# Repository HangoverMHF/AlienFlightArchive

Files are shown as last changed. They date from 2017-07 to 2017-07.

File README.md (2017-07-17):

## NOTE: This is an archival copy of the original CC BY-SA AlienFlight flight controllers. Preserved for posterity.

# AlienFlight

| [Classic FC](/Flight-Controllers/Classic#narrow-classic-flight-controller) | [F3 Quad FC](/Flight-Controllers/F3-V1/F3-Quad#f3-quad-brushed-v1-flight-controller) | [F3 Hexa FC](/Flight-Controllers/F3-V1/F3-Hexa#f3-hexa-brushed-v1-flight-controller) | [F3 Octo FC](/Flight-Controllers/F3-V1/F3-Octo#f3-octo-brushed-v1-flight-controller) |

## Objective

The goal of the AlienFlight project is to share some of my personal flight controller designs with fellow RC hobbyists, in hopes that this work might be useful. I want others to use, learn from, and enjoy this work in the same ways I have.

MAKE, SHARE, FLY!

### Contributing

Do you want to give back to this project? This project needs people who can help by providing:

* Board Specifications
* Documentation and Images
* How To tutorials

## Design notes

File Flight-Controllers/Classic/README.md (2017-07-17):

## NOTE: This is an archival copy of the original CC BY-SA AlienFlight flight controllers. Preserved for posterity.

## Narrow Classic Flight Controller
The Classic Narrow is an experimental flight controller designed to pilot Quadcopters using 7mm-8.5mm brushed motors. It features an Atmel Atmega 32u4 processor, MPU6050 Gyro/Accelerometer,  built in 9.5A ESCs, and a built in Bind button for easy binding.
### Narrow Classic Example Picture

Classic Narrow Classic-Narrow

#### Narrow Classic Specs
* MultiWii compatible
* Atmel Atmega 32u4 micro controller
* MPU6050 accelerometer/gyro sensor unit
* 4x 9.5A brushed ESCs (MOSFETS) - 2oz copper layers recommended
* Integrated USB port (side access)
* Serial connection for external DSM2/DSMX sat receiver (e.g. Spektrum SAT, OrangeRx R100 or Lemon RX)
* Alternate PPM connection for external receiver - Pin pulled out - untested
* Hardware bind button for easy binding
* Motor connections are at the corners for easy orientation with reduced wiring
* Dimensions:  31x25mm
* Direct operation from an single cell 3.7V Lipo battery
* 5V and 3.3V buck/boost regulators (5V out can be used to power accessories)
* Buzzer out on pin D8
* Single Sided - all components on the top layer

#### Build Files and Resources:

Schematic and board design ➜ [Narrow Classic 5V Eagle CAD Files](/Flight-Controllers/Classic "Classic Narrow Eagle CAD Files") 

This bare board can be made at ➜ [OSH Park](https://oshpark.com/ "OSH Park")

Stencils can be made at ➜ [OSH Stencils](https://www.oshstencils.com/ "OSH Stencils")

_**THESE FILES ARE BEING PROVIDED ''AS IS'' WITHOUT ANY EXPRESS OR IMPLIED WARRANTIES.**_

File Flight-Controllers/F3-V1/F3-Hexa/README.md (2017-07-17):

## NOTE: This is an archival copy of the original CC BY-SA AlienFlight flight controllers. Preserved for posterity.

## F3 Hexa Brushed V1 Flight Controller

The F3 Brushed Hexa is an experimental flight controller designed to pilot Quadcopters or Hexacopters using 7mm-8.5mm brushed motors. It features an ARM STM32 F3 processor, built in side USB for easy firmware flashing, and parameter editing, MPU6050 Gyro/Accelerometer, dual channel 5A ESCs, and a built in Bind switch for hassle free binding.

### F3 Hexa Brushed V1 Example Picture
(JMPR build pictured - Latest build uses tactile switches in place of jumpers)

F3 Hexa Brushed V1

#### F3 Hexa Brushed V1 Specifications

* Cleanflight/Betaflight compatible
* STM32 F3 MCU
* MPU6050 accelerometer/gyro sensor unit
* 4X dual channel 5A brushed ESCs (Mosfets)- 2oz copper layers recommended
* Direct programming connection via side USB
* (*) serial connection for external DSM2/DSMX sat receiver (e.g. Spektrum SAT, OrangeRx R100 or Lemon RX)
* Alternate PPM receiver connection (i.e. Deltang Rx31)
* Hardware bind button for easy binding
* Boot bind button for easy firmware flashing
* Motor connections oriented for self explanatory connection
* Dimensions: 27x31mm (use thin FR4 material for weight savings)
* Direct operation from an single cell lipo battery

#### Build Files and Resources:

Schematic and board design ➜ [F3 Hexa Brushed V1 Eagle CAD Files](/Flight-Controllers/F3-V1/F3-Hexa "F3 Hexa Brushed V1 Eagle CAD Files") 

This bare board can be made at ➜ [OSH Park](https://oshpark.com/ "OSH Park")

Stencils can be made at ➜ [OSH Stencils](https://www.oshstencils.com/ "OSH Stencils")

_**THESE FILES ARE BEING PROVIDED ''AS IS'' WITHOUT ANY EXPRESS OR IMPLIED WARRANTIES.**_

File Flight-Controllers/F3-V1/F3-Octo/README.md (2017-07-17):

## NOTE: This is an archival copy of the original CC BY-SA AlienFlight flight controllers. Preserved for posterity.

## F3 Octo Brushed V1 Flight Controller

The F3 Brushed Octo V1 is an experimental flight controller designed to pilot Quadcopters, Hexacopters, and even Octocopters using 7mm-8.5mm brushed motors. It features an ARM STM32 F3 processor,  built in USB for easy firmware flashing, and parameter editing,  MPU6050 Gyro/Accelerometer, 7A ESCs, and a built in Bind switch for easy binding.
### F3 Octo Brushed V1 Example Picture
(JMPR build pictured - Latest build uses tactile switches in place of jumpers)

F3 Octo Brushed V1

#### F3 Octo Brushed V1 Specifications

* Cleanflight compatible
* STM32 F3 MCU
* MPU6050 accelerometer/gyro sensor unit
* 4x 7A dual channel brushed ESCs (Mosfets) - 2 oz copper layers recommended
* Direct programming connection via side USB
* (*) serial connection for external DSM2/DSMX sat receiver (e.g. Spektrum SAT, OrangeRx R100 or Lemon RX)
* Alternate PPM receiver connection (i.e. Deltang Rx31)
* Hardware bind button for easy binding
* Boot button for easy firmware flashing
* Motor connections oriented for self explanatory connection
* Dimensions: 29x33mm (use thin FR4 material for weight savings)
* Direct operation from an single cell lipo battery
* All components arranged on the top layer

**NOTES:** Battery Voltage monitoring on 1S powered machines is not very effective (and is disabled by default in Cleanflight F3 firmware).

**Lost Model Alarm:** A small Buzzer with a low current draw (=<20mA) can be used in place of the VMON LED.  You can tie activation of this Buzzer to a switch on your Transmitter via the Beeper option, on the Cleanflight modes page.

**Octo Configuration:** In order to use Octo. you must select the custom mixer option on the Cleanflight Configuration page. Physical motor outputs are self explanatory.

#### Build Files and Resources:

Schematic and board design ➜ [F3 Octo Brushed V1 Eagle CAD Files](/Flight-Controllers/F3-V1/F3-Octo "F3 Octo Brushed V1 Eagle CAD Files") 

This bare board can be made at ➜ [OSH Park](https://oshpark.com/ "OSH Park")

Stencils can be made at ➜ [OSH Stencils](https://www.oshstencils.com/ "OSH Stencils")

_**THESE FILES ARE BEING PROVIDED ''AS IS'' WITHOUT ANY EXPRESS OR IMPLIED WARRANTIES.**_

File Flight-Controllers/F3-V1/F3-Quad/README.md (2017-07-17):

## NOTE: This is an archival copy of the original CC BY-SA AlienFlight flight controllers. Preserved for posterity.

## F3 Quad Brushed V1 Flight Controller

The F3 Quad Brushed V1 is an experimental flight controller designed to pilot Quadcopters using 7mm-8.5mm brushed motors. It features an ARM STM32 F3 processor, built in side USB for easy firmware flashing, and parameter editing, MPU6050 Gyro/Accelerometer, 9.5A ESCs, and a built in Bind button for hassle free transmitter binding.

### F3 Quad Brushed V1 Example Picture 
(JMPR build pictured - Latest build uses tactile switches in place of jumpers)

F3 Quad Brushed V1

#### F3 Quad Brushed V1 Specifications

* Cleanflight/Betaflight compatible
* STM32 F3 MCU
* MPU6050 accelerometer/gyro sensor unit
* 4x 9.5A brushed ESCs (Mosfets) - 2oz copper recommended
* Direct programming connection via Side USB
* (*) serial connection for external DSM2/DSMX sat receiver (e.g. Spektrum SAT, OrangeRx R100 or Lemon RX)
* Alternate PPM receiver connection (i.e. Deltang Rx31)
* Hardware bind button for easy binding
* Boot button for easy firmware flashing
* Motor connections oriented for self explanatory connection
* Dimensions: 26x30mm (use thin FR4 material for weight savings)
* Direct operation from an single cell lipo battery
* All components arranged on the top layer

#### Build Files and Resources:

Schematic and board design ➜ [F3 Quad Brushed V1 Eagle CAD Files](/Flight-Controllers/F3-V1/F3-Quad "F3 Quad Brushed V1 Eagle CAD Files") 

This bare board can be made at ➜ [OSH Park](https://oshpark.com/ "OSH Park")

Stencils can be made at ➜ [OSH Stencils](https://www.oshstencils.com/ "OSH Stencils")

_**THESE FILES ARE BEING PROVIDED ''AS IS'' WITHOUT ANY EXPRESS OR IMPLIED WARRANTIES.**_

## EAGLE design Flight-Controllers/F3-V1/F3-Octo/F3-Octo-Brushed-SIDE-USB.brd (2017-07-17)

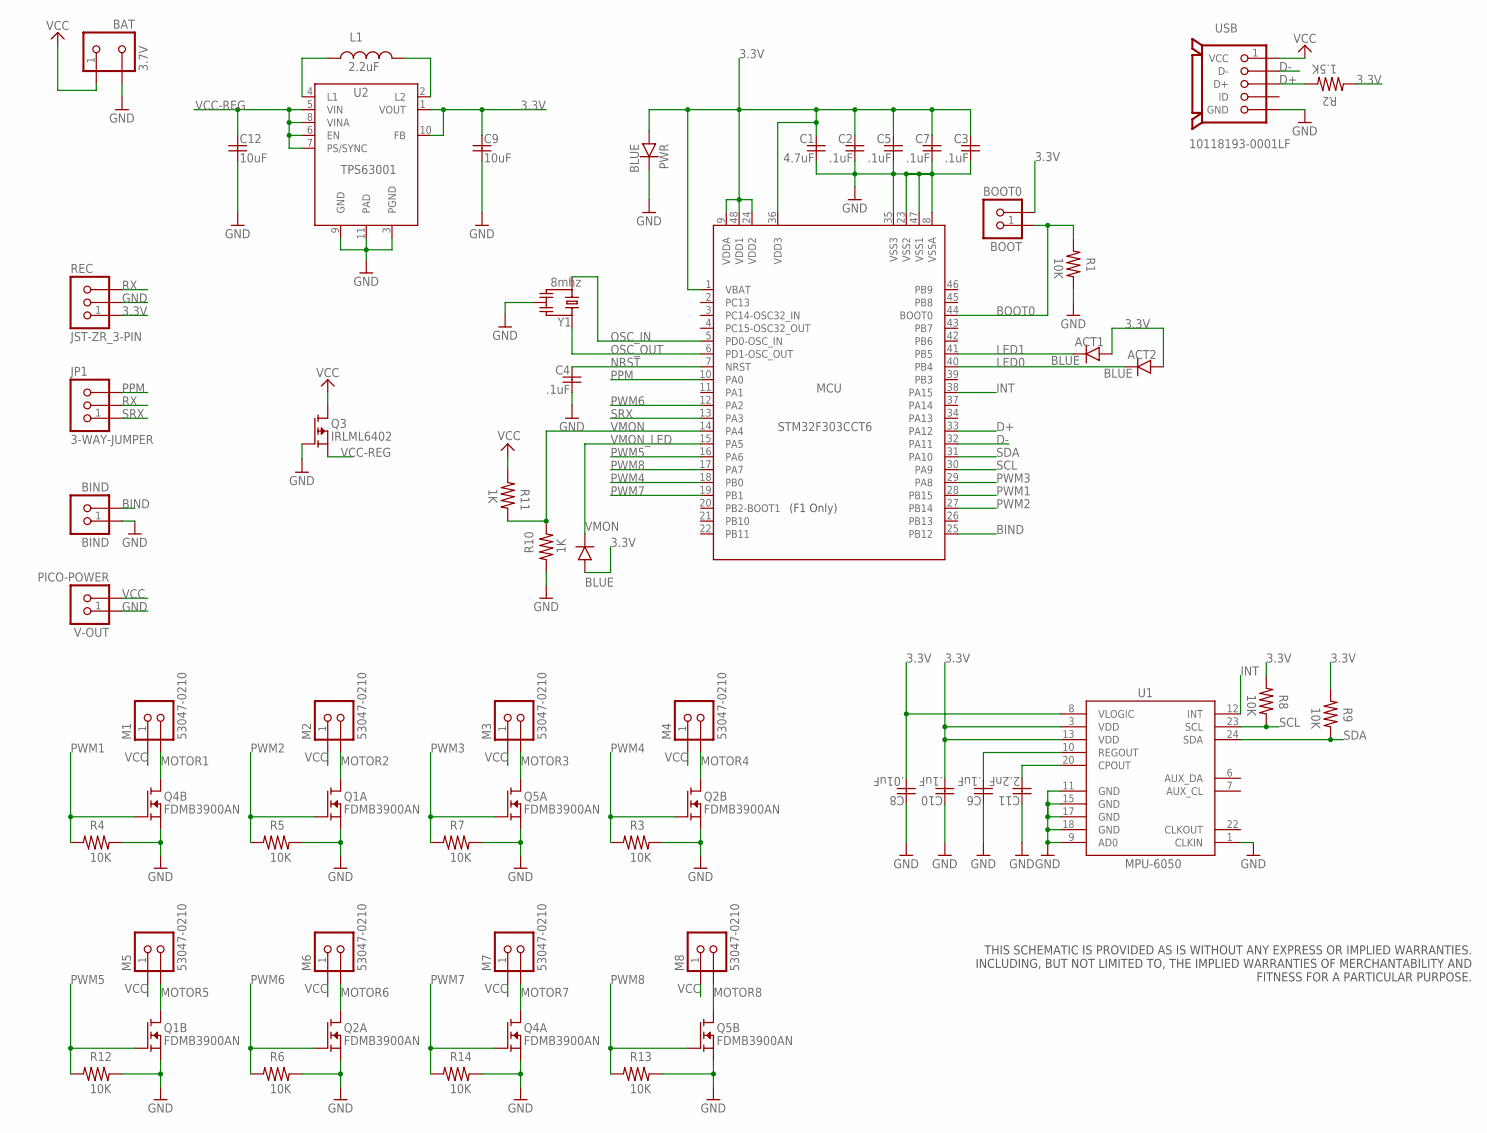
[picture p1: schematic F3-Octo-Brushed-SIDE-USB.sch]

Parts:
ACT1, ACT2: BLUE; SMD-CHIP-LED-0805
BAT: 3.7V; S2B-PH-K-S
BIND: BIND; B3U-1000P(M)
BOOT: BOOT0; B3U-1000P(M)
C1: 4.7uF; MUR-CAP-0603
C2, C3, C4, C5, C6, C7, C10: .1uF; MUR-CAP-0603
C8: .01uF; MUR-CAP-0603
C9, C12: 10uF; YUDEN-CAP-0805
C11: 2.2nF; MUR-CAP-0603
JP1: 3-WAY-JUMPER
L1: 2.2uF; NR301X
M1, M2, M3, M4, M5, M6, M7, M8: 53047-0210; PICO-53047-02
MCU: STM32F303CCT6; LQFP48-7X7
PWR: BLUE; SMD-CHIP-LED-0805
Q1, Q2, Q4, Q5: FDMB3900AN; 8-WDFN-DUAL
Q3: IRLML6402; SOT-23
R1, R3, R4, R5, R6, R7, R8, R9, R12, R13, R14: 10K; VISH-RES-0603
R2: 1.5K; VISH-RES-0603
R10, R11: 1K; VISH-RES-0603
REC: JST-ZR_3-PIN; S3B-ZR
U1: MPU-6050; QFN24-4X4
U2: TPS63001; VSON-N10
USB: 10118193-0001LF
V-OUT: PICO-POWER; PICO_1.25_.5MM
VMON: BLUE; SMD-CHIP-LED-0805
Y1: 8mhz; RESONATOR_8

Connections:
3.3V: ACT1.A, ACT2.A, BOOT.2, C1.1, C2.1, C3.1, C5.1, C7.1, C8.2, C9.1, C10.2, MCU.1 (VBAT), MCU.9 (VDDA), MCU.24 (VDD2), MCU.36 (VDD3), MCU.48 (VDD1), PWR.A, R2.2, R8.2, R9.2, REC.1, U1.3 (VDD), U1.8 (VLOGIC), U1.13 (VDD), U2.1 (VOUT), U2.10 (FB), VMON.A
BIND: BIND.2, MCU.25 (PB12)
BOOT0: BOOT.1, MCU.44 (BOOT0), R1.2
D+: MCU.33 (PA12), R2.1, USB.3 (D+)
D-: MCU.32 (PA11), USB.2 (D-)
GND: BAT.2, BIND.1, C1.2, C2.2, C3.2, C4.2, C5.2, C6.1, C7.2, C8.1, C9.2, C10.1, C11.1, C12.2, MCU.8 (VSSA), MCU.23 (VSS2), MCU.35 (VSS3), MCU.47 (VSS1), PWR.C, Q1.1@S1 (S), Q1.3@S1 (S), Q2.1@S1 (S), Q2.3@S1 (S), Q3.1 (G), Q4.1@S1 (S), Q4.3@S1 (S), Q5.1@S1 (S), Q5.3@S1 (S), R1.1, R3.1, R4.1, R5.1, R6.1, R7.1, R10.2, R12.1, R13.1, R14.1, REC.2, U1.1 (CLKIN), U1.9 (AD0), U1.11 (GND), U1.15 (GND), U1.17 (GND), U1.18 (GND), U2.3 (PGND), U2.9 (GND), U2.11 (PAD), USB.5 (GND), USB.GND, USB.GND2 (GND), USB.HOLE1 (GND), USB.HOLE2 (GND), V-OUT.1, Y1.2
INT: MCU.38 (PA15), U1.12 (INT)
LED0: ACT2.C, MCU.40 (PB4)
LED1: ACT1.C, MCU.41 (PB5)
MOTOR1: M1.2, Q4.5+6 (D)
MOTOR2: M2.2, Q1.7+8 (D)
MOTOR3: M3.2, Q5.7+8 (D)
MOTOR4: M4.2, Q2.5+6 (D)
MOTOR5: M5.2, Q1.5+6 (D)
MOTOR6: M6.2, Q2.7+8 (D)
MOTOR7: M7.2, Q4.7+8 (D)
MOTOR8: M8.2, Q5.5+6 (D)
unnamed: C6.2, U1.10 (REGOUT)
unnamed: C11.2, U1.20 (CPOUT)
unnamed: L1.2, U2.2 (L2)
unnamed: L1.1, U2.4 (L1)
NRST: C4.1, MCU.7 (NRST)
OSC_IN: MCU.5 (PD0-OSC_IN), Y1.3
OSC_OUT: MCU.6 (PD1-OSC_OUT), Y1.1
PPM: JP1.3, MCU.10 (PA0)
PWM1: MCU.28 (PB15), Q4.4@G2 (G), R4.2
PWM2: MCU.27 (PB14), Q1.2@G1 (G), R5.2
PWM3: MCU.29 (PA8), Q5.2@G1 (G), R7.2
PWM4: MCU.18 (PB0), Q2.4@G2 (G), R3.2
PWM5: MCU.16 (PA6), Q1.4@G2 (G), R12.2
PWM6: MCU.12 (PA2), Q2.2@G1 (G), R6.2
PWM7: MCU.19 (PB1), Q4.2@G1 (G), R14.2
PWM8: MCU.17 (PA7), Q5.4@G2 (G), R13.2
RX: JP1.2, REC.3
SCL: MCU.30 (PA9), R8.1, U1.23 (SCL)
SDA: MCU.31 (PA10), R9.1, U1.24 (SDA)
SRX: JP1.1, MCU.13 (PA3)
VCC: BAT.1, M1.1, M2.1, M3.1, M4.1, M5.1, M6.1, M7.1, M8.1, Q3.3 (D), R11.2, USB.1 (VCC), V-OUT.2
VCC-REG: C12.1, Q3.2 (S), U2.5 (VIN), U2.6 (EN), U2.7 (PS/SYNC), U2.8 (VINA)
VMON: MCU.14 (PA4), R10.1, R11.1
VMON_LED: MCU.15 (PA5), VMON.C

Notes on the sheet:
THIS SCHEMATIC IS PROVIDED AS IS WITHOUT ANY EXPRESS OR IMPLIED WARRANTIES. INCLUDING, BUT NOT LIMITED TO, THE IMPLIED WARRANTIES OF MERCHANTABILITY AND FITNESS FOR A PARTICULAR PURPOSE.

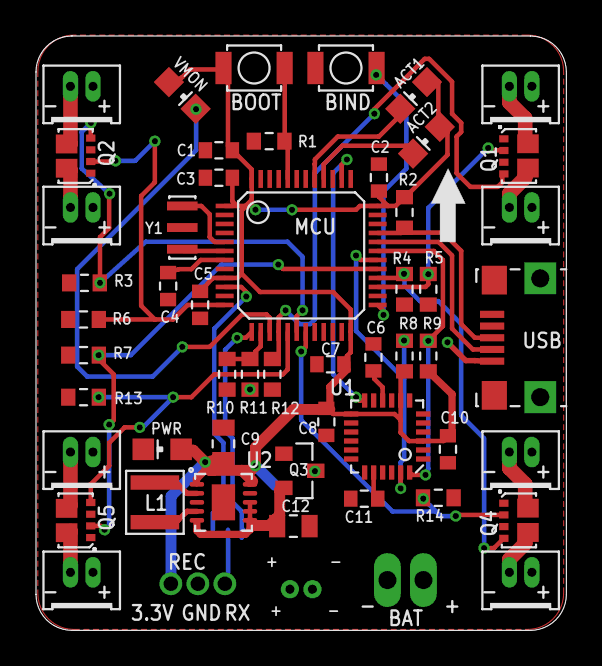
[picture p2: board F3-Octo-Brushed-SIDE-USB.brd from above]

Board: 2 copper layers, 29.5 x 33.0 mm, 56 parts (1 on the bottom side), 41 nets.

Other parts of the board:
U$2: ARROW

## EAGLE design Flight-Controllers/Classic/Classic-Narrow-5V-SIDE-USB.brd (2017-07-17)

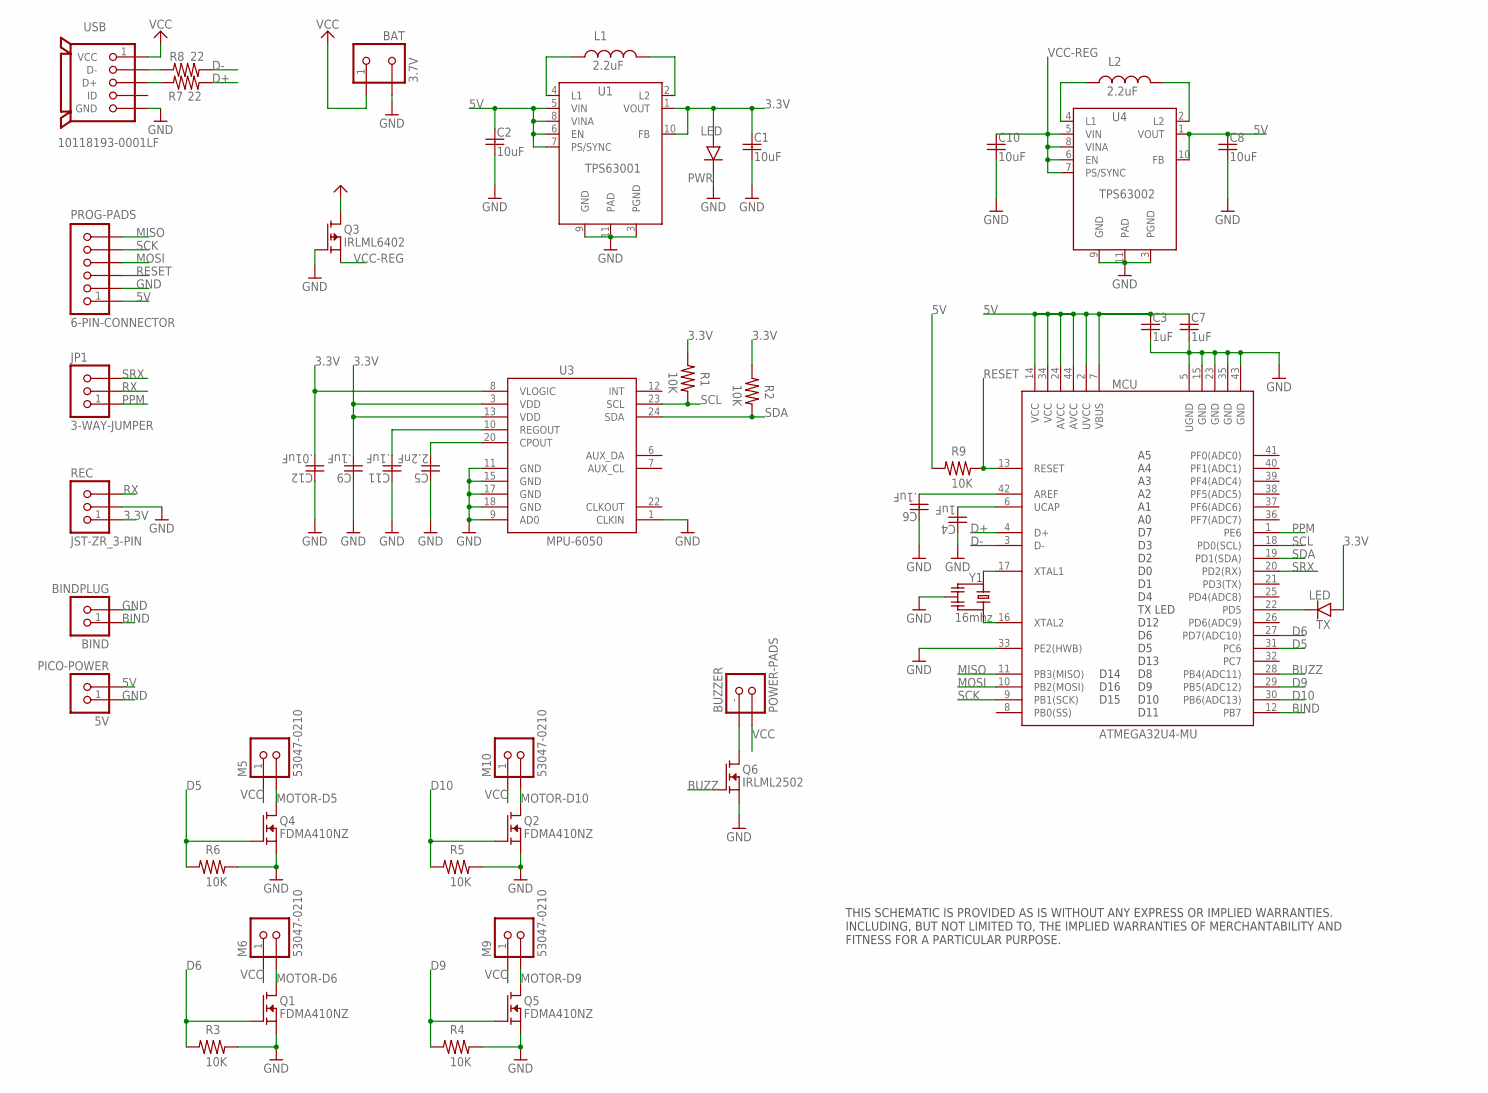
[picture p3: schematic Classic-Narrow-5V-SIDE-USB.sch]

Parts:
5V: PICO-POWER; PICO_1.25_.5MM
BAT: 3.7V; S2B-PH-K-S
BIND: BINDPLUG; B3U-1000P(M)
BUZZER: POWER-PADS; POW-PADS
C1, C2, C8, C10: 10uF; YUDEN-CAP-0805
C3, C4, C7: 1uF; MUR-CAP-0603
C5: 2.2nF; MUR-CAP-0603
C6, C9, C11: .1uF; MUR-CAP-0603
C12: .01uF; MUR-CAP-0603
JP1: 3-WAY-JUMPER
L1, L2: 2.2uF; NR301X
M5, M6, M9, M10: 53047-0210; PICO-53047-02
MCU: ATMEGA32U4-MU; QFN44-7X7
PROG-PADS: 6-PIN-CONNECTOR; B6B-ZR
PWR: LED; SMD-CHIP-LED-0805
Q1, Q2, Q4, Q5: FDMA410NZ; MICROFET-2X2
Q3: IRLML6402; SOT-23
Q6: IRLML2502; SOT-23
R1, R2, R3, R4, R5, R6, R9: 10K; VISH-RES-0603
R7, R8: 22; VISH-RES-0603
REC: JST-ZR_3-PIN; S3B-ZR
TX: LED; SMD-CHIP-LED-0805
U1: TPS63001; VSON-N10
U3: MPU-6050; QFN24-4X4
U4: TPS63002; VSON-N10
USB: 10118193-0001LF
Y1: 16mhz; RESONATOR_16

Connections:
3.3V: C1.1, C9.2, C12.2, PWR.A, R1.2, R2.2, REC.1, TX.A, U1.1 (VOUT), U1.10 (FB), U3.3 (VDD), U3.8 (VLOGIC), U3.13 (VDD)
5V: 5V.2, C2.1, C3.1, C7.1, C8.1, MCU.2 (UVCC), MCU.7 (VBUS), MCU.14 (VCC), MCU.24 (AVCC), MCU.34 (VCC), MCU.44 (AVCC), PROG-PADS.1, R9.2, U1.5 (VIN), U1.6 (EN), U1.7 (PS/SYNC), U1.8 (VINA), U4.1 (VOUT), U4.10 (FB)
AREF: C6.2, MCU.42 (AREF)
BIND: BIND.1, MCU.12 (PB7)
BUZZ: MCU.28 (PB4(ADC11)), Q6.1 (G)
D5: MCU.31 (PC6), Q4.G, R6.2
D6: MCU.27 (PD7(ADC10)), Q1.G, R3.2
D9: MCU.29 (PB5(ADC12)), Q5.G, R4.2
D10: MCU.30 (PB6(ADC13)), Q2.G, R5.2
D+: MCU.4 (D+), R7.1
D-: MCU.3 (D-), R8.1
GND: 5V.1, BAT.2, BIND.2, C1.2, C2.2, C3.2, C4.1, C5.1, C6.1, C7.2, C8.2, C9.1, C10.2, C11.1, C12.1, MCU.5 (UGND), MCU.15 (GND), MCU.23 (GND), MCU.33 (PE2(HWB)), MCU.35 (GND), MCU.43 (GND), PROG-PADS.2, PWR.C, Q1.S, Q1.S1 (S), Q2.S, Q2.S1 (S), Q3.1 (G), Q4.S, Q4.S1 (S), Q5.S, Q5.S1 (S), Q6.2 (S), R3.1, R4.1, R5.1, R6.1, REC.2, U1.3 (PGND), U1.9 (GND), U1.11 (PAD), U3.1 (CLKIN), U3.9 (AD0), U3.11 (GND), U3.15 (GND), U3.17 (GND), U3.18 (GND), U4.3 (PGND), U4.9 (GND), U4.11 (PAD), USB.5 (GND), USB.GND, USB.GND2 (GND), USB.HOLE1 (GND), USB.HOLE2 (GND), Y1.2
MISO: MCU.11 (PB3(MISO)), PROG-PADS.6
MOSI: MCU.10 (PB2(MOSI)), PROG-PADS.4
MOTOR-D5: M5.2, Q4.D, Q4.D1 (D), Q4.D2 (D), Q4.D3 (D), Q4.D4 (D)
MOTOR-D6: M6.2, Q1.D, Q1.D1 (D), Q1.D2 (D), Q1.D3 (D), Q1.D4 (D)
MOTOR-D9: M9.2, Q5.D, Q5.D1 (D), Q5.D2 (D), Q5.D3 (D), Q5.D4 (D)
MOTOR-D10: M10.2, Q2.D, Q2.D1 (D), Q2.D2 (D), Q2.D3 (D), Q2.D4 (D)
unnamed: MCU.17 (XTAL1), Y1.1
unnamed: MCU.16 (XTAL2), Y1.3
unnamed: R7.2, USB.3 (D+)
unnamed: C4.2, MCU.6 (UCAP)
unnamed: C11.2, U3.10 (REGOUT)
unnamed: R8.2, USB.2 (D-)
unnamed: MCU.22 (PD5), TX.C
unnamed: C5.2, U3.20 (CPOUT)
unnamed: L1.2, U1.2 (L2)
unnamed: BUZZER.- (1), Q6.3 (D)
unnamed: L1.1, U1.4 (L1)
unnamed: L2.2, U4.2 (L2)
unnamed: L2.1, U4.4 (L1)
PPM: JP1.1, MCU.1 (PE6)
RESET: MCU.13 (RESET), PROG-PADS.3, R9.1
RX: JP1.2, REC.3
SCK: MCU.9 (PB1(SCK)), PROG-PADS.5
SCL: MCU.18 (PD0(SCL)), R1.1, U3.23 (SCL)
SDA: MCU.19 (PD1(SDA)), R2.1, U3.24 (SDA)
SRX: JP1.3, MCU.20 (PD2(RX))
VCC: BAT.1, BUZZER.+ (2), M5.1, M6.1, M9.1, M10.1, Q3.3 (D), USB.1 (VCC)
VCC-REG: C10.1, Q3.2 (S), U4.5 (VIN), U4.6 (EN), U4.7 (PS/SYNC), U4.8 (VINA)

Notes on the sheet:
THIS SCHEMATIC IS PROVIDED AS IS WITHOUT ANY EXPRESS OR IMPLIED WARRANTIES. INCLUDING, BUT NOT LIMITED TO, THE IMPLIED WARRANTIES OF MERCHANTABILITY AND FITNESS FOR A PARTICULAR PURPOSE.

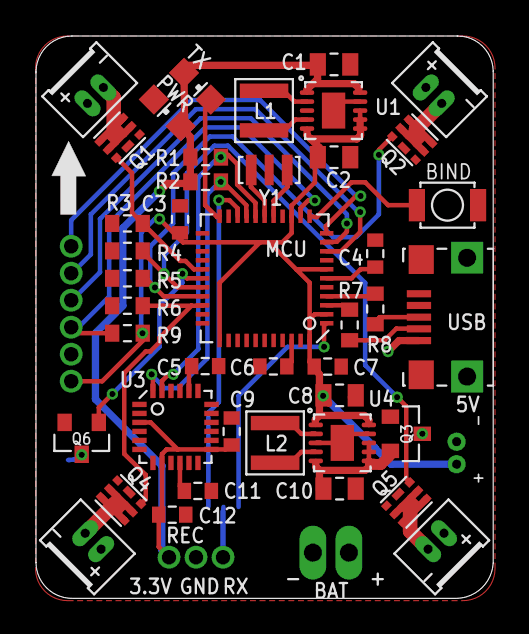
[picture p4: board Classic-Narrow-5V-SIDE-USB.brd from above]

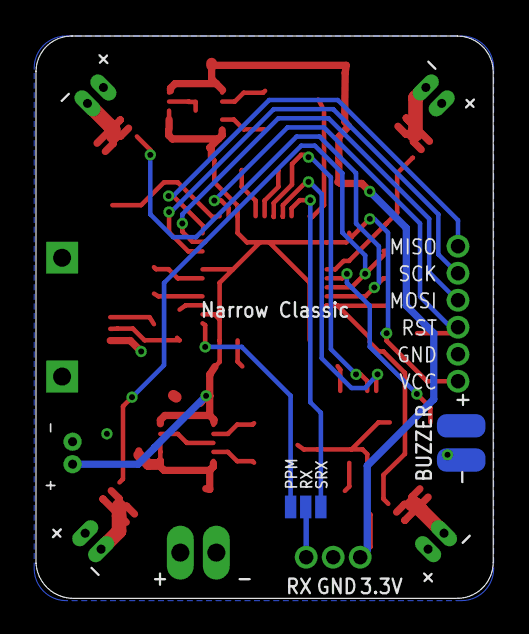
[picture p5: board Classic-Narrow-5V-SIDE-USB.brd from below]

Board: 2 copper layers, 25.4 x 31.2 mm, 49 parts (2 on the bottom side), 40 nets.

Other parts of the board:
U$1: ARROW

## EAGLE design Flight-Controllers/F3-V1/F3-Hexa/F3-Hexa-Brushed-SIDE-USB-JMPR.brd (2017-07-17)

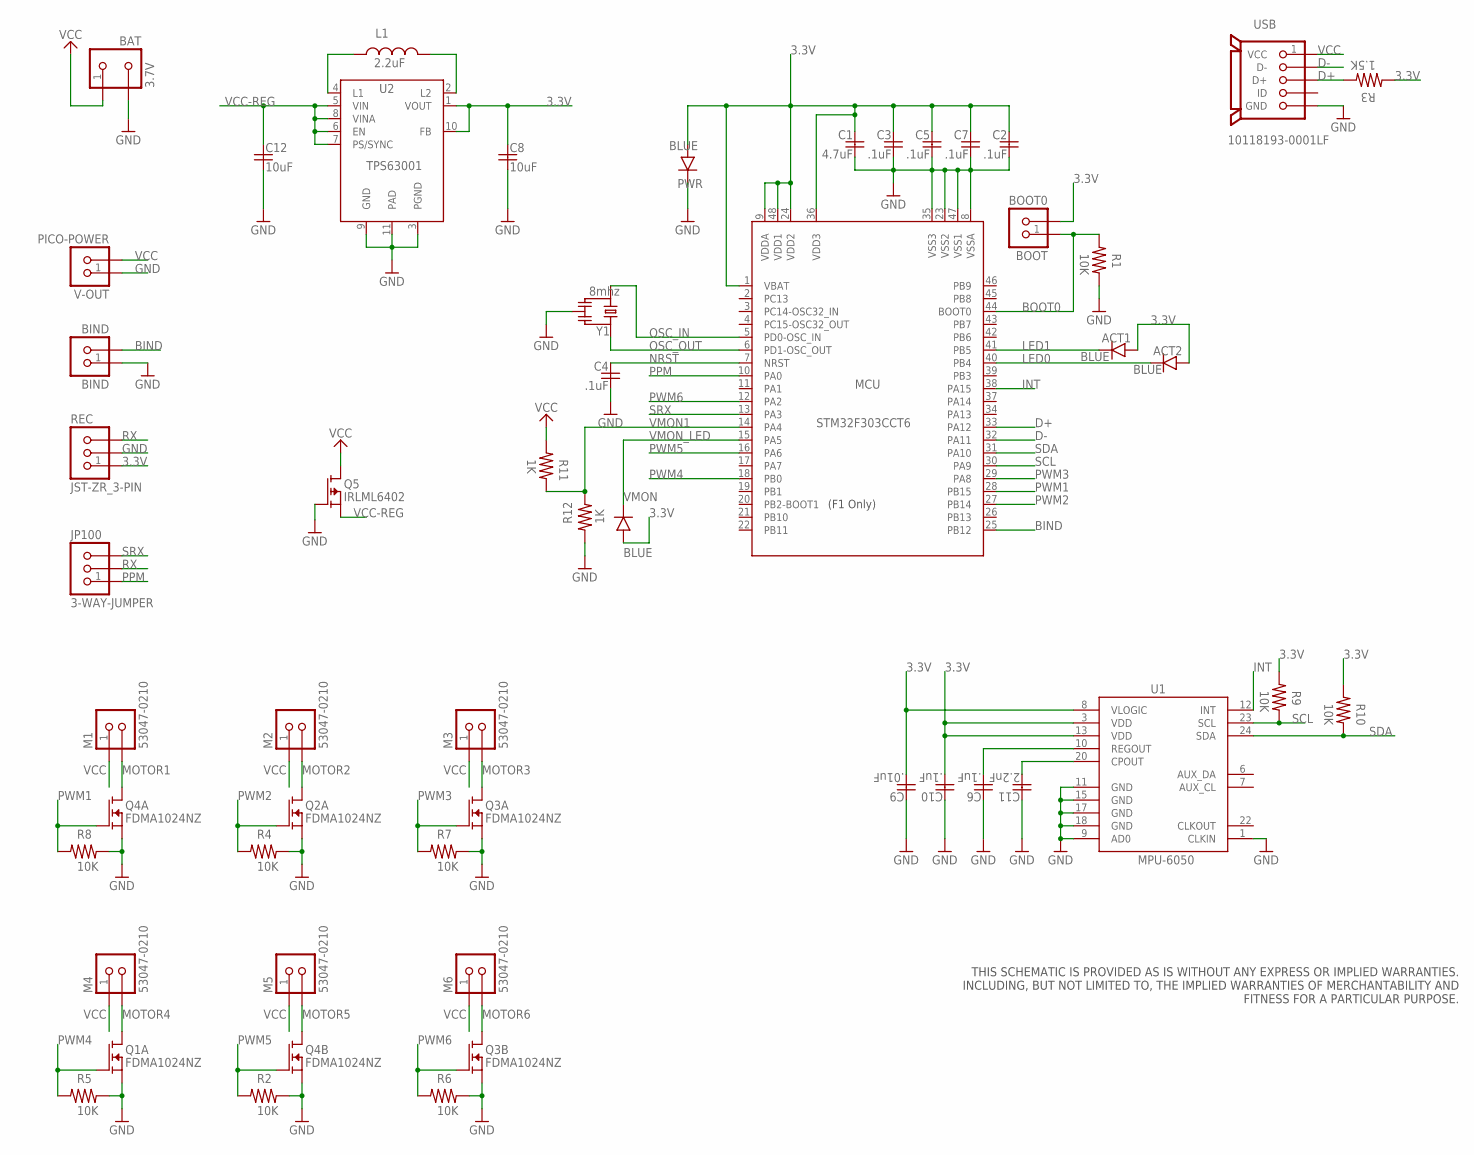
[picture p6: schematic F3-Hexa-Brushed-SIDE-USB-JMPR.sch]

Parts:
ACT1, ACT2: BLUE; SMD-CHIP-LED-0805
BAT: 3.7V; S2B-PH-K-S
BIND: BIND; 1.27MM-PINHEADX2
BOOT: BOOT0; 1.27MM-PINHEADX2
C1: 4.7uF; MUR-CAP-0603
C2, C3, C4, C5, C6, C7, C10: .1uF; MUR-CAP-0603
C8, C12: 10uF; YUDEN-CAP-0805
C9: .01uF; MUR-CAP-0603
C11: 2.2nF; MUR-CAP-0603
JP100: 3-WAY-JUMPER
L1: 2.2uF; NR301X
M1, M2, M3, M4, M5, M6: 53047-0210; PICO-53047-02
MCU: STM32F303CCT6; LQFP48-7X7
PWR: BLUE; SMD-CHIP-LED-0805
Q1, Q2, Q3, Q4: FDMA1024NZ; MICROFET-2X2_DUAL
Q5: IRLML6402; SOT-23
R1, R2, R4, R5, R6, R7, R8, R9, R10: 10K; VISH-RES-0603
R3: 1.5K; VISH-RES-0603
R11, R12: 1K; VISH-RES-0603
REC: JST-ZR_3-PIN; S3B-ZR
U1: MPU-6050; QFN24-4X4
U2: TPS63001; VSON-N10
USB: 10118193-0001LF
V-OUT: PICO-POWER; PICO_1.25_.5MM
VMON: BLUE; SMD-CHIP-LED-0805
Y1: 8mhz; RESONATOR_8

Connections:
3.3V: ACT1.A, ACT2.A, BOOT.2, C1.1, C2.1, C3.1, C5.1, C7.1, C8.1, C9.2, C10.2, MCU.1 (VBAT), MCU.9 (VDDA), MCU.24 (VDD2), MCU.36 (VDD3), MCU.48 (VDD1), PWR.A, R3.2, R9.2, R10.2, REC.1, U1.3 (VDD), U1.8 (VLOGIC), U1.13 (VDD), U2.1 (VOUT), U2.10 (FB), VMON.A
BIND: BIND.2, MCU.25 (PB12)
BOOT0: BOOT.1, MCU.44 (BOOT0), R1.2
D+: MCU.33 (PA12), R3.1, USB.3 (D+)
D-: MCU.32 (PA11), USB.2 (D-)
GND: BAT.2, BIND.1, C1.2, C2.2, C3.2, C4.2, C5.2, C6.1, C7.2, C8.2, C9.1, C10.1, C11.1, C12.2, MCU.8 (VSSA), MCU.23 (VSS2), MCU.35 (VSS3), MCU.47 (VSS1), PWR.C, Q1.A.S (S), Q2.A.S (S), Q3.A.S (S), Q3.B.S (S), Q4.A.S (S), Q4.B.S (S), Q5.1 (G), R1.1, R2.1, R4.1, R5.1, R6.1, R7.1, R8.1, R12.2, REC.2, U1.1 (CLKIN), U1.9 (AD0), U1.11 (GND), U1.15 (GND), U1.17 (GND), U1.18 (GND), U2.3 (PGND), U2.9 (GND), U2.11 (PAD), USB.5 (GND), USB.GND, USB.GND2 (GND), USB.HOLE1 (GND), USB.HOLE2 (GND), V-OUT.1, Y1.2
INT: MCU.38 (PA15), U1.12 (INT)
LED0: ACT2.C, MCU.40 (PB4)
LED1: ACT1.C, MCU.41 (PB5)
MOTOR1: M1.2, Q4.A.D (D), Q4.A.D1 (D)
MOTOR2: M2.2, Q2.A.D (D), Q2.A.D1 (D)
MOTOR3: M3.2, Q3.A.D (D), Q3.A.D1 (D)
MOTOR4: M4.2, Q1.A.D (D), Q1.A.D1 (D)
MOTOR5: M5.2, Q4.B.D (D), Q4.B.D1 (D)
MOTOR6: M6.2, Q3.B.D (D), Q3.B.D1 (D)
unnamed: C6.2, U1.10 (REGOUT)
unnamed: C11.2, U1.20 (CPOUT)
unnamed: L1.2, U2.2 (L2)
unnamed: L1.1, U2.4 (L1)
NRST: C4.1, MCU.7 (NRST)
OSC_IN: MCU.5 (PD0-OSC_IN), Y1.3
OSC_OUT: MCU.6 (PD1-OSC_OUT), Y1.1
PPM: JP100.1, MCU.10 (PA0)
PWM1: MCU.28 (PB15), Q4.A.G (G), R8.2
PWM2: MCU.27 (PB14), Q2.A.G (G), R4.2
PWM3: MCU.29 (PA8), Q3.A.G (G), R7.2
PWM4: MCU.18 (PB0), Q1.A.G (G), R5.2
PWM5: MCU.16 (PA6), Q4.B.G (G), R2.2
PWM6: MCU.12 (PA2), Q3.B.G (G), R6.2
RX: JP100.2, REC.3
SCL: MCU.30 (PA9), R9.1, U1.23 (SCL)
SDA: MCU.31 (PA10), R10.1, U1.24 (SDA)
SRX: JP100.3, MCU.13 (PA3)
VCC: BAT.1, M1.1, M2.1, M3.1, M4.1, M5.1, M6.1, Q5.3 (D), R11.2, USB.1 (VCC), V-OUT.2
VCC-REG: C12.1, Q5.2 (S), U2.5 (VIN), U2.6 (EN), U2.7 (PS/SYNC), U2.8 (VINA)
VMON1: MCU.14 (PA4), R11.1, R12.1
VMON_LED: MCU.15 (PA5), VMON.C

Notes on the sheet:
THIS SCHEMATIC IS PROVIDED AS IS WITHOUT ANY EXPRESS OR IMPLIED WARRANTIES. INCLUDING, BUT NOT LIMITED TO, THE IMPLIED WARRANTIES OF MERCHANTABILITY AND FITNESS FOR A PARTICULAR PURPOSE.

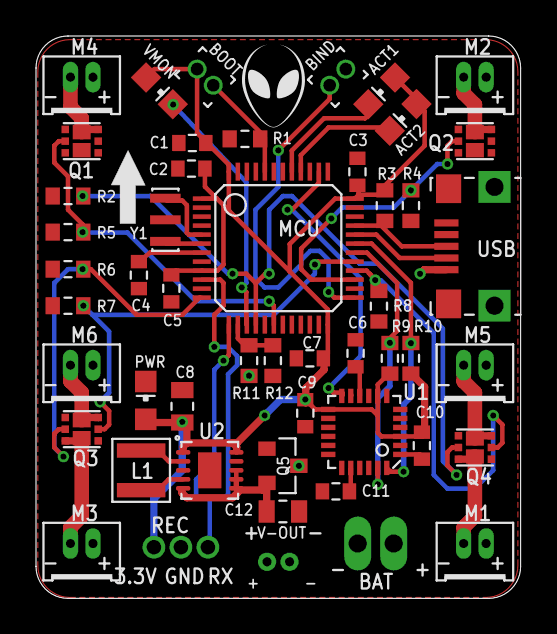
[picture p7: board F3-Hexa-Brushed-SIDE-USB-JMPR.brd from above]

Board: 2 copper layers, 26.9 x 31.2 mm, 53 parts (1 on the bottom side), 37 nets.

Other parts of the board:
U$1: ARROW
U$2: ALIENHEADSMALL

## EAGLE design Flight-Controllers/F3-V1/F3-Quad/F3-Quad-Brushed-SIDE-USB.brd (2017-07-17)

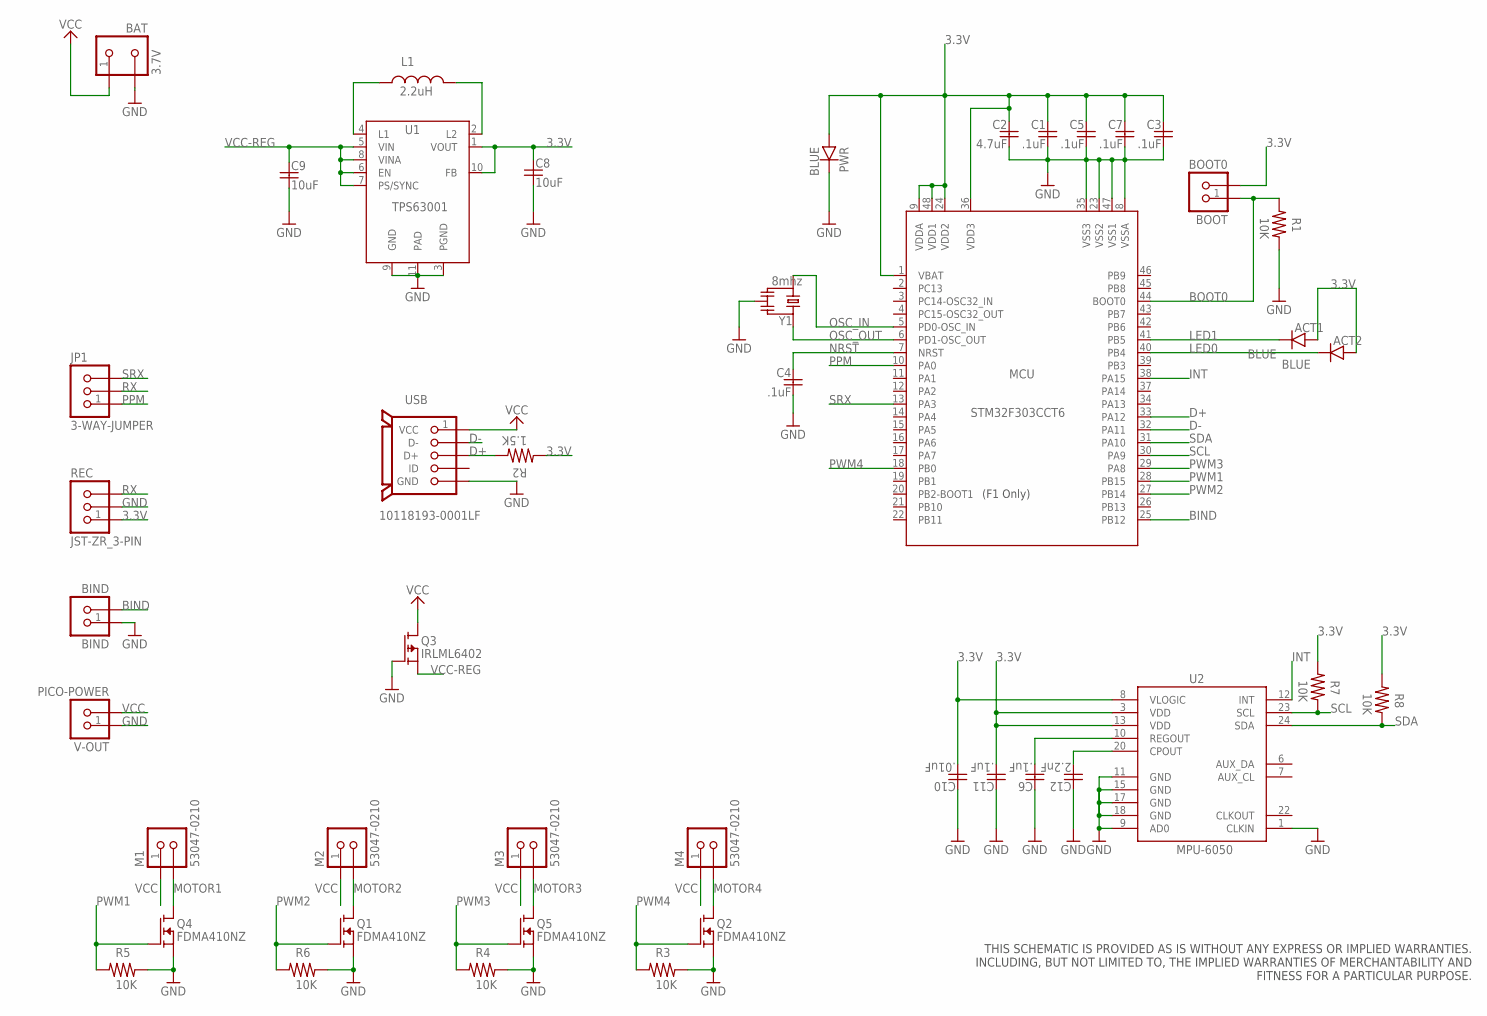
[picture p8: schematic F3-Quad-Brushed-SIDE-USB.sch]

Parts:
ACT1, ACT2: BLUE; SMD-CHIP-LED-0805
BAT: 3.7V; S2B-PH-K-S
BIND: BIND; B3U-1000P(M)
BOOT: BOOT0; B3U-1000P(M)
C1, C3, C4, C5, C6, C7, C11: .1uF; MUR-CAP-0603
C2: 4.7uF; MUR-CAP-0603
C8, C9: 10uF; YUDEN-CAP-0805
C10: .01uF; MUR-CAP-0603
C12: 2.2nF; MUR-CAP-0603
JP1: 3-WAY-JUMPER
L1: 2.2uH; NR301X
M1, M2, M3, M4: 53047-0210; PICO-53047-02
MCU: STM32F303CCT6; LQFP48-7X7
PWR: BLUE; SMD-CHIP-LED-0805
Q1, Q2, Q4, Q5: FDMA410NZ; MICROFET-2X2
Q3: IRLML6402; SOT-23
R1, R3, R4, R5, R6, R7, R8: 10K; VISH-RES-0603
R2: 1.5K; VISH-RES-0603
REC: JST-ZR_3-PIN; S3B-ZR
U1: TPS63001; VSON-N10
U2: MPU-6050; QFN24-4X4
USB: 10118193-0001LF
V-OUT: PICO-POWER; PICO_1.25_.5MM
Y1: 8mhz; RESONATOR_8

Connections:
3.3V: ACT1.A, ACT2.A, BOOT.2, C1.1, C2.1, C3.1, C5.1, C7.1, C8.1, C10.2, C11.2, MCU.1 (VBAT), MCU.9 (VDDA), MCU.24 (VDD2), MCU.36 (VDD3), MCU.48 (VDD1), PWR.A, R2.2, R7.2, R8.2, REC.1, U1.1 (VOUT), U1.10 (FB), U2.3 (VDD), U2.8 (VLOGIC), U2.13 (VDD)
BIND: BIND.2, MCU.25 (PB12)
BOOT0: BOOT.1, MCU.44 (BOOT0), R1.2
D+: MCU.33 (PA12), R2.1, USB.3 (D+)
D-: MCU.32 (PA11), USB.2 (D-)
GND: BAT.2, BIND.1, C1.2, C2.2, C3.2, C4.2, C5.2, C6.1, C7.2, C8.2, C9.2, C10.1, C11.1, C12.1, MCU.8 (VSSA), MCU.23 (VSS2), MCU.35 (VSS3), MCU.47 (VSS1), PWR.C, Q1.S, Q1.S1 (S), Q2.S, Q2.S1 (S), Q3.1 (G), Q4.S, Q4.S1 (S), Q5.S, Q5.S1 (S), R1.1, R3.1, R4.1, R5.1, R6.1, REC.2, U1.3 (PGND), U1.9 (GND), U1.11 (PAD), U2.1 (CLKIN), U2.9 (AD0), U2.11 (GND), U2.15 (GND), U2.17 (GND), U2.18 (GND), USB.5 (GND), USB.GND, USB.GND2 (GND), USB.HOLE1 (GND), USB.HOLE2 (GND), V-OUT.1, Y1.2
INT: MCU.38 (PA15), U2.12 (INT)
LED0: ACT2.C, MCU.40 (PB4)
LED1: ACT1.C, MCU.41 (PB5)
MOTOR1: M1.2, Q4.D, Q4.D1 (D), Q4.D2 (D), Q4.D3 (D), Q4.D4 (D)
MOTOR2: M2.2, Q1.D, Q1.D1 (D), Q1.D2 (D), Q1.D3 (D), Q1.D4 (D)
MOTOR3: M3.2, Q5.D, Q5.D1 (D), Q5.D2 (D), Q5.D3 (D), Q5.D4 (D)
MOTOR4: M4.2, Q2.D, Q2.D1 (D), Q2.D2 (D), Q2.D3 (D), Q2.D4 (D)
unnamed: C6.2, U2.10 (REGOUT)
unnamed: C12.2, U2.20 (CPOUT)
unnamed: L1.2, U1.2 (L2)
unnamed: L1.1, U1.4 (L1)
NRST: C4.1, MCU.7 (NRST)
OSC_IN: MCU.5 (PD0-OSC_IN), Y1.3
OSC_OUT: MCU.6 (PD1-OSC_OUT), Y1.1
PPM: JP1.1, MCU.10 (PA0)
PWM1: MCU.28 (PB15), Q4.G, R5.2
PWM2: MCU.27 (PB14), Q1.G, R6.2
PWM3: MCU.29 (PA8), Q5.G, R4.2
PWM4: MCU.18 (PB0), Q2.G, R3.2
RX: JP1.2, REC.3
SCL: MCU.30 (PA9), R7.1, U2.23 (SCL)
SDA: MCU.31 (PA10), R8.1, U2.24 (SDA)
SRX: JP1.3, MCU.13 (PA3)
VCC: BAT.1, M1.1, M2.1, M3.1, M4.1, Q3.3 (D), USB.1 (VCC), V-OUT.2
VCC-REG: C9.1, Q3.2 (S), U1.5 (VIN), U1.6 (EN), U1.7 (PS/SYNC), U1.8 (VINA)

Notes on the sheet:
THIS SCHEMATIC IS PROVIDED AS IS WITHOUT ANY EXPRESS OR IMPLIED WARRANTIES. INCLUDING, BUT NOT LIMITED TO, THE IMPLIED WARRANTIES OF MERCHANTABILITY AND FITNESS FOR A PARTICULAR PURPOSE.

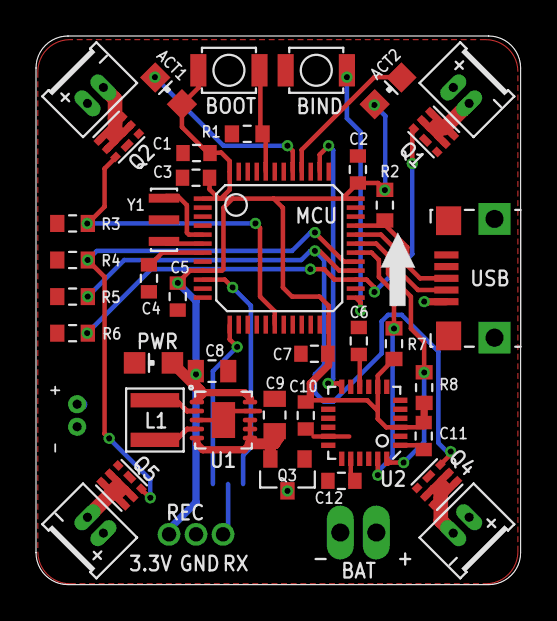
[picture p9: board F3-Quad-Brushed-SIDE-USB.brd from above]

Board: 2 copper layers, 26.9 x 30.5 mm, 45 parts (1 on the bottom side), 31 nets.

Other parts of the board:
U$2: ARROW

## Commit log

2017-07-17 * Binary zip files arent' the best use of github revision control. Expanded into text and XML files. * TODO: ensure compatibility with latest version of Autodesk Eagle
    [Classic-Narrow-5V-SIDE-USB-JMPR.brd, Classic-Narrow-5V-SIDE-USB-JMPR.sch, Classic-Narrow-5V-SIDE-USB.brd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]
2017-07-17 * Many archival links result in 404 page not found. Replaced with links to OSH Park where board file can be uploaded to fabricate. Minor tidying..

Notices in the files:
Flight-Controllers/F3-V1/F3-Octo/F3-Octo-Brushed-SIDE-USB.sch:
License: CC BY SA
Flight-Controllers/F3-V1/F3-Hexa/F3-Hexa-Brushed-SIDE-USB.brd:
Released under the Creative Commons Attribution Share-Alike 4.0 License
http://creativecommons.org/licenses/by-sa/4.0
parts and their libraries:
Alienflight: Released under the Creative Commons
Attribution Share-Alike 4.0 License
